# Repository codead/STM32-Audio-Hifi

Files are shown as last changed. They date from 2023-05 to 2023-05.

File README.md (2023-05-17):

# STM32 Audio Hifi with FreeRTOS
If you have any questions, please contact me via:
- email: duchuylee@gmail.com
- facebook: https://www.facebook.com/duchuy.le.33/

## Description:
 *[Open Source] DIY Hifi player with STM32.*
 
 *This project builds a hifi player based on the STM32F411CEU6 microcontroller with full options.*
 
 *All HW & SW is open source.*
 ### Hardware:
  + MCU: STM32F411CEU6 with 100MHz, 512kB flash, 128kB SRAM.
  + Audio codec IC: WM8960 hifi audio with 44.1KHz, 16 bits data.
  + LCD display: 1.3" 240x240 IPS display with ST7789 IC.
  + Battery charge IC: BQ24073 -  Standalone 1-Cell 1.5-A Linear Battery Chargers with Power Path.
  + Battery monitor IC: STC3100 - Battery monitor IC with Coulomb counter/gas gauge.
  + Power management IC: TPS63001 - 96% Buck-Boost Converter with 1.7A Current Switches, 3.3V fixed Output voltage in 3x3 QFN.
  + IO control button & LED: SX1509B
  + Storage & backup: SDIO MicroSD, W25Q80.
  + USB: USB type C full speed.
  ### Software:
  + Run FreeRTOS on STM32CubeIDE

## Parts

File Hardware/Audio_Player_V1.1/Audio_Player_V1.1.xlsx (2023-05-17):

Comment | Description | Designator | Footprint | LibRef | Quantity
Battery | Multicell Battery | BT1 | BAT-2 | Battery | 1
1uF | Cap SMD | C1, C4, C21, C22 | Cap 0603 | Cap | 4
10uF | Cap SMD | C2, C3, C7, C14, C18, C27, C28, C31, C37, C47, C48 | Cap 0603 | Cap | 11
220nF | Cap SMD | C5 | Cap 0603 | Cap | 1
100nF | Cap SMD | C8, C9, C10, C11, C12, C13, C19, C20, C23, C24, C25, C26, C29, C30, C34, C38, C39, C40, C41, C42, C43, C44, C45, C46 | Cap 0603 | Cap | 24
2.2uF | Cap SMD | C15 | Cap 0603 | Cap | 1
12pF | Cap SMD | C16, C17 | Cap 0603 | Cap | 2
100uF-10V | Cap SMD | C32, C33 | Cap 1210 | Cap | 2
220pF | Cap SMD | C35, C36 | Cap 0603 | Cap | 2
Jack Audio 4 PJ-342-4.5H | Jack Audio 3.5 4 pole CTIA use for: Samsung, Apple, Sony | J1 | PJ-342 | Jack Audio 4 PJ-342-4.5H | 1
Jump 1mm | Jump 1mm | JP1 | Jump 1mm | Jump | 1
2R2uH | L- SMD | L1 | Inductor 0520 | Inductor | 1
LED | LED | LD1 | LED | LED | 1
Header 2x2 | Header 2x2 | P1, P2, P3, P4 | Header 2mm 2x2 | Header 2x2 | 4
10k | Res SMD | R1 | Res 0603 | Res | 1
1k1-1% | Res SMD | R2 | Res 0603 | Res | 1
1k3-1% | Res SMD | R3 | Res 0603 | Res | 1
47k-1% | Res SMD | R4 | Res 0603 | Res | 1
1k5-1% | Res SMD | R5, R6, R36 | Res 0603 | Res | 3
1k-1% | Res SMD | R7, R8, R37 | Res 0603 | Res | 3
10R-1% | Res SMD | R9, R10, R18, R19, R20, R21 | Res 0603 | Res | 6
10k-1% | Res SMD | R11, R12, R13, R14, R15, R16, R17, R24, R25, R26, R27, R29, R30 | Res 0603 | Res | 13
33k-1% | Res SMD | R22 | Res 0603 | Res | 1
0R-1% | Res SMD | R23 | Res 0603 | Res | 1
200k-1% | Res SMD | R28 | Res 0603 | Res | 1
330R-1% | Res SMD | R31, R32, R33, R34, R35 | Res 0603 | Res | 5
0.05R-1% | Res SMD | R38 | Res 2512 | Res | 1
100R-1% | Res SMD | R39 | Res 0603 | Res | 1
Switch | MSK-38 Slide switch 3 pin | SW1 | Slide switch MSK-38 | SW 3 | 1
Switch 5 ways | Switch 5 ways: left, right, up, down, centre | SW2 | Switch 5 ways | Switch 5 ways | 1
TP | TP | TP1, TP2, TP3, TP4, TP5, TP6 | TP | TP | 6
BQ24073 | Li-Ion Battery Charger | U1 | QFN-16 | BQ24073 | 1
STC3100IQT | Battery monitor IC with Coulomb counter/gas gauge | U2 | DFN-8 3x3 | STC3100 | 1
STM32F411CEU6 | UFQFPN48 Arm® Cortex®-M4 32b MCU+FPU, 125 DMIPS, 512KB Flash, 128KB RAM, USB OTG FS, 11 TIMs, 1 ADC, 13 comm. interfaces | U3 | UFQFPN-48 | STM32F411CEU6 | 1
MicroSD | MicroSD Push-Push A | U4 | MicroSD A | MicroSD-A | 1
WM8960 | Stereo CODEC with 1W Stereo Class D Speaker Drivers and Headphone Drivers for Portable Audio Applications | U5 | QFN-32 5X5 | WM8960 | 1
TPS63001 | TPS6300x High-Efficient Single Inductor Buck-Boost Converter With 1.8-A Switches | U6 | VSON-10 3x3 | TPS63001 | 1
W25Qxx | Flash Memory SPI Interface | U7 | WSON 6x5 | W25Qxx | 1
SX1509B | SX1509B 16-channel I2C GPIO with LED Driver and Keypad Engine | U8 | QFN-28 4x4 | SX1509B | 1
USB type C | USB type C 16 Pins | USB1 | USB Type C | USB type C | 1
25Mhz | Xtal 4 pins SMD | XT1 | Crystal 3225 | XT4 | 1
OSC 24MHz | Xtal - OSC | XT2 | Crystal 3225 | XTAL- 4 Pins | 1

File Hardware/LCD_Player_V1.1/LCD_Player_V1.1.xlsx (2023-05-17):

Comment | Description | Designator | Footprint | LibRef | Quantity
100nF | Cap SMD | C1 | Cap 0603 | Cap | 1
1uF | Cap SMD | C2 | Cap 0603 | Cap | 1
LCD 1.3" 240 X 240 IPS DISPLAY | This is a general LCD display Module, IPS screen, 1.3inch diagonal, 240*240 resolution, with embedded controller, communicating via SPI interface | LCD1 | LCD 1.3inch IPS HD | LCD 1.3" 240 X 240 IPS DISPLAY | 1
TP | TP | LN, LP, RN, RP, TP1 | TP | TP | 5
Header 2x2 | Header 2x2 | P1, P2, P3, P4 | Header 2mm 2x2 | Header 2x2 | 4
C1815 | NPN 600mW, ECB | Q1 | SOT23B | C1815 | 1
1k-1% | Res SMD | R1 | Res 0603 | Res | 1
10k-1% | Res SMD | R2 | Res 0603 | Res | 1
10R-1% | Res SMD | R3 | Res 0603 | Res | 1
100k | Adjust Resistor | VR1 | Adjust Resistor Wheel | Res Adjust | 1

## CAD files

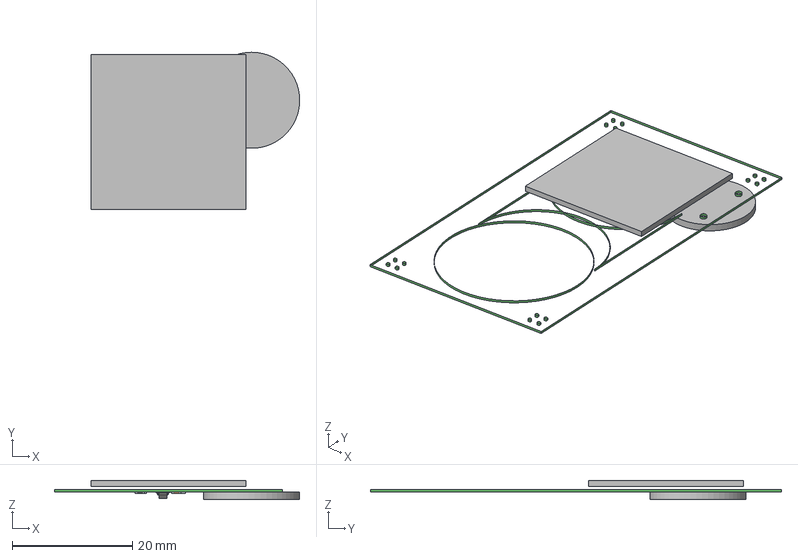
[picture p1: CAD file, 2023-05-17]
Hardware/LCD_Player_V1.1/LCD_Player_V1.1.step
40.9 x 68.4 x 3.18 mm
Extruded
SW3DPS-SOT-23-DEFAULT
Resistor0603 x 3
0603_SMD_Capacitor x 2

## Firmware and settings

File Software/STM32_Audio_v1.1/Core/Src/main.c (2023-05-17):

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
/* Includes ------------------------------------------------------------------*/
#include "main.h"
#include "cmsis_os.h"
#include "adc.h"
#include "crc.h"
#include "dma.h"
#include "fatfs.h"
#include "i2c.h"
#include "i2s.h"
#include "sdio.h"
#include "spi.h"
#include "tim.h"
#include "usart.h"
#include "gpio.h"

/* USER CODE BEGIN Includes */
#include <stdio.h>
#include "ST7789.h"
#include "Draw.h"
#include "Display.h"
#include "WM8960.h"
#include "Play_wav.h"
#include "Volume.h"
#include "SX1509B.h"
#include "IO_Expand.h"
#include "FileManager.h"
#include "STC3100.h"
#include "Setting.h"
#include "W25Qxx.h"
#include "Database.h"
#include "Utilities.h"
// This just demo
/* USER CODE END Includes */

/* USER CODE BEGIN PD */
#define USE_DEBUG_UART
/* USER CODE END PD */


void SystemClock_Config(void);
void MX_FREERTOS_Init(void);
/* USER CODE BEGIN 0 */
extern STC3100_INFO Batt;
extern uint32_t volumeDigital;
extern DISPLAY Display;
extern __SETTING Setting;
/* USER CODE END 0 */

/**
  * @brief  The application entry point.
  * @retval int
  */
int main(void)
{
  /* USER CODE BEGIN 1 */
  HAL_StatusTypeDef res = HAL_OK;
  /* USER CODE END 1 */

  /* MCU Configuration--------------------------------------------------------*/

  /* Reset of all peripherals, Initializes the Flash interface and the Systick. */
  HAL_Init();

  /* Configure the system clock */
  SystemClock_Config();

  /* Initialize all configured peripherals */
  MX_GPIO_Init();
  MX_DMA_Init();
  MX_USART1_UART_Init();
  MX_SPI1_Init();
  MX_I2C1_Init();
  MX_I2S5_Init();
  MX_SDIO_SD_Init();
  MX_FATFS_Init();
  MX_TIM3_Init();
  MX_ADC1_Init();
  MX_CRC_Init();
  MX_TIM2_Init();
  /* USER CODE BEGIN 2 */
  ST7789_Init();
  printf("Initialize successfully\n");
//  res = SX1509B_Init();

  res = IO_Expand_Init();
  if(res == HAL_OK)
  {
    printf("SX1509B_Init complete !!!\r\n");
  }
  else
  {
    printf("SX1509B_Init fail ! Error code: %d\r\n", res);
  }
  res = STC3100_Init();
  if(res == HAL_OK)
  {
    printf("STC3100_Init complete !!!\r\n");
  }
  else
  {
    printf("STC3100_Init fail ! Error code: %d\r\n", res);
  }
  res = STC3100_Get(&Batt, BATTERY_PROP_VOLTAGE_NOW);
  //res = WM8960_Init();
  res = WM8960_Init_PLL();
  if(res == HAL_OK)
  {
    printf("WM89060_Init complete !!!\r\n");
  }
  else
  {
    printf("WM89060_Init fail ! Error code: %d\r\n", res);
  }
  ScanSDCard();
  Setting_Init();
  W25Qxx_Init();
  Database_LoadData();
  ListMusic_Init();
  HAL_TIM_Base_Start_IT(&htim3);
  //MX_TouchGFX_Init();
  /* USER CODE END 2 */

  /* Call init function for freertos objects (in freertos.c) */
  MX_FREERTOS_Init();

  /* Start scheduler */
  osKernelStart();

  /* We should never get here as control is now taken by the scheduler */
  /* Infinite loop */
  /* USER CODE BEGIN WHILE */
  while (1)
  {
    /* USER CODE END WHILE */

    /* USER CODE BEGIN 3 */
  }
  /* USER CODE END 3 */
}

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
/* USER CODE BEGIN 4 */

extern void touchgfxSignalVSync(void);
#ifdef __GNUC__
  /* With GCC/RAISONANCE, small printf (option LD Linker->Libraries->Small printf
     set to 'Yes') calls __io_putchar() */
  #define PUTCHAR_PROTOTYPE int __io_putchar(int ch)
#else
  #define PUTCHAR_PROTOTYPE int fputc(int ch, FILE *f)
#endif /* __GNUC__ */
/**
  * @brief  Retargets the C library printf function to the USART.
  * @param  None
  * @retval None
  */
PUTCHAR_PROTOTYPE
{
  /* Place your implementation of fputc here */
  /* e.g. write a character to the EVAL_COM1 and Loop until the end of transmission */
#ifdef USE_DEBUG_UART
  HAL_UART_Transmit(&huart1, (uint8_t *)&ch, 1, 0xFFFF);
#endif
  return ch;
}
/* USER CODE END 4 */

/**
  * @brief  Period elapsed callback in non blocking mode
  * @note   This function is called  when TIM5 interrupt took place, inside
  * HAL_TIM_IRQHandler(). It makes a direct call to HAL_IncTick() to increment
  * a global variable "uwTick" used as application time base.
  * @param  htim : TIM handle
  * @retval None
  */
void HAL_TIM_PeriodElapsedCallback(TIM_HandleTypeDef *htim)
{
  /* USER CODE BEGIN Callback 0 */
  if (htim->Instance == TIM2)
  {
    // update current music time
    Display.CurrentTime++;
    //printf("Display.CurrentTime = %ld\n", Display.CurrentTime);
    if(Display.CurrentTime > 0 && Display.CurrentTime > Display.DurationTime)
    {
      Display.CurrentTime = 0;
      HAL_TIM_Base_Stop_IT(&htim2);
    }
    Display.NeedToUpdateCurrentTime = true;
    //touchgfxSignalVSync();
    // LCD back light
    if(Setting.Always_Display == false)
    {
      if(Display.LCDBacklightStatus == true)
      {
        Display.LCDBackLightTime--;
        if(Display.LCDBackLightTime == 0)
        {
          LCD_BackLight_Off();
          Display.LCDBackLightTime = 20;
          Display.LCDBacklightStatus = false;
        }
      }
    }
    // invisible volume
    if(Display.NeedToInvisibleVolume == true)
    {
      Display.TimeForDisplayVolume++;
      if(Display.TimeForDisplayVolume == 5)
      {
        Display.NeedToInvisibleVolume = 0;
        Display.NeedToInvisibleVolume = false;
        Draw_VolumeInvisible();
      }
    }
  }
  // Use for calculate random variable & ADC period
  if(htim->Instance == TIM3)
  {
#if (SELECT_RANDOM == USE_MANUAL_TIMER)
    IncreaseCounter();
#endif
    HAL_ADC_Start_DMA(&hadc1, &volumeDigital, 1);
  }
  /* USER CODE END Callback 0 */
  if (htim->Instance == TIM5) {
    HAL_IncTick();
  }
}

/**
  * @brief  This function is executed in case of error occurrence.
  * @retval None
  */
void Error_Handler(void)
{
  /* USER CODE BEGIN Error_Handler_Debug */
  /* User can add his own implementation to report the HAL error return state */
  __disable_irq();
  while (1)
  {
  }
  /* USER CODE END Error_Handler_Debug */
}

#ifdef  USE_FULL_ASSERT
/**
  * @brief  Reports the name of the source file and the source line number
  *         where the assert_param error has occurred.
  * @param  file: pointer to the source file name
  * @param  line: assert_param error line source number
  * @retval None
  */
void assert_failed(uint8_t *file, uint32_t line)
{
  /* USER CODE BEGIN 6 */
  /* User can add his own implementation to report the file name and line number,
     ex: printf("Wrong parameters value: file %s on line %d\r\n", file, line) */
  /* USER CODE END 6 */
}
#endif /* USE_FULL_ASSERT */

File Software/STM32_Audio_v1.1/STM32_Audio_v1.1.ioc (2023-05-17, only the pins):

Mcu.UserName=STM32F411CEUx
PA0-WKUP.Signal=GPIO_Output
PA1.Signal=GPIO_Output
PA10.Signal=I2S5_SD
PA13.Signal=SYS_JTMS-SWDIO
PA14.Signal=SYS_JTCK-SWCLK
PA2.Signal=GPXTI2
PA3.GPIO_Label=Volume
PA3.Signal=ADCx_IN3
PA4.GPIO_Label=FLASH_CS
PA4.Signal=GPIO_Output
PA5.Signal=SPI1_SCK
PA6.Signal=SDIO_CMD
PA7.Signal=SPI1_MOSI
PA8.Signal=SDIO_D1
PA9.Signal=SDIO_D2
PB0.Signal=I2S5_CK
PB1.Signal=I2S5_WS
PB13.GPIO_Label=BAT_CHARGE
PB13.Signal=GPXTI13
PB14.Signal=GPIO_Input
PB15.Signal=SDIO_CK
PB3.Signal=USART1_RX
PB4.Signal=SPI1_MISO
PB5.Signal=SDIO_D3
PB6.Signal=USART1_TX
PB7.Signal=SDIO_D0
PB8.Signal=I2C1_SCL
PB9.Signal=I2C1_SDA
PC13-ANTI_TAMP.Signal=GPIO_Output
PC14-OSC32_IN.Signal=GPIO_Output
PC15-OSC32_OUT.Signal=GPIO_Output

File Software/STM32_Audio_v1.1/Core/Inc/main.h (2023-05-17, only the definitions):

#define ST7789_RST_GPIO_Port	GPIOC
#define ST7789_RST_Pin			GPIO_PIN_13
#define ST7789_DC_GPIO_Port		GPIOC
#define ST7789_DC_Pin			GPIO_PIN_15
#define ST7789_CS_GPIO_Port		GPIOA
#define ST7789_CS_Pin			GPIO_PIN_0
#define ST7789_BL_GPIO_Port  GPIOC
#define ST7789_BL_Pin      GPIO_PIN_14
#define SX1509B_GPIO_Port  GPIOA
#define SX1509B_RST_Pin    GPIO_PIN_1
#define SX1509B_INT_Pin    GPIO_PIN_2
#define W25Qxx_CS_GPIO_Port GPIOA
#define W25Qxx_CS_Pin GPIO_PIN_4
#define Volume_Pin GPIO_PIN_3
#define Volume_GPIO_Port GPIOA
#define FLASH_CS_Pin GPIO_PIN_4
#define FLASH_CS_GPIO_Port GPIOA
#define BAT_CHARGE_Pin GPIO_PIN_13
#define BAT_CHARGE_GPIO_Port GPIOB
#define BAT_CHARGE_EXTI_IRQn EXTI15_10_IRQn

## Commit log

2023-05-17 Add source HW & SW
    First commit
    [Audio.SchDoc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]
2023-05-17 Add schematic
    Add schematic

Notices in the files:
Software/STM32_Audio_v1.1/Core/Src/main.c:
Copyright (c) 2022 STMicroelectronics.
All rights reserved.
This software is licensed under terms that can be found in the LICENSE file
